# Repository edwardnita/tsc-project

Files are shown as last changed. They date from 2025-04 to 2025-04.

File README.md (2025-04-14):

# OpenBook - eBook Reader

**Autor:** Nita Eduard-Eugen
**Data:** 06 Aprilie 2025, updated pe 14 Aprilie 2025

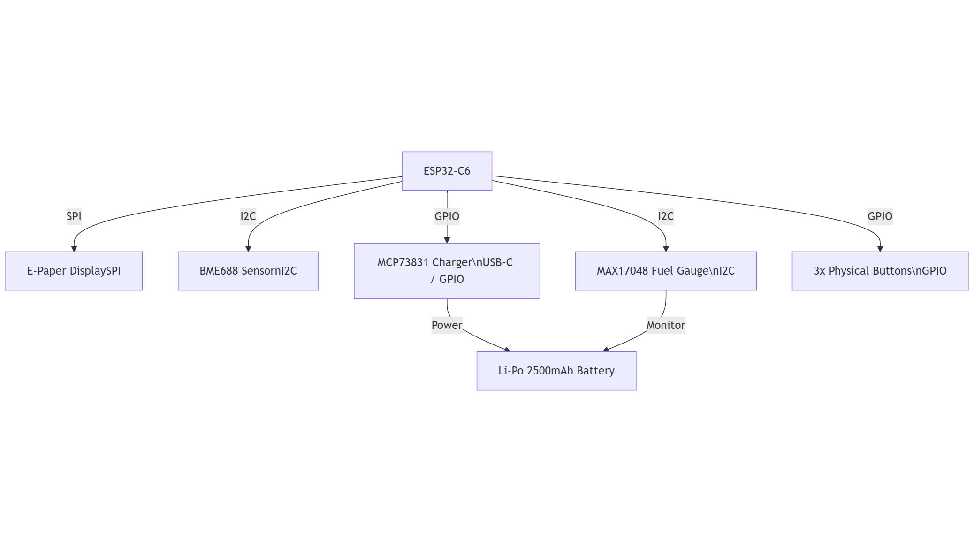
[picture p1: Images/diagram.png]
block_diagram


## Bill of Materials (BOM)

| Component | Link | Datasheet |
|:---|:---|:---|
| BME680 | [Link](https://www.snapeda.com/parts/BME680/Bosch/view-part/?welcome=home) | [Datasheet](https://www.bosch-sensortec.com/media/boschsensortec/downloads/datasheets/bst-bme680-ds001.pdf) |
| BUTTON | [Link](https://industry.panasonic.com/global/en/products/control/switch/light-touch/number/evqpuj02k) | [Datasheet](https://www.lcsc.com/datasheet/lcsc_datasheet_2201121800_PANASONIC-EVQPUJ02K_C2936858.pdf) |
| R0402 | [Link](https://componentsearchengine.com/part-view/R0402%201%25%20100%20K%20(RC0402FR-07100KL)/YAGEO) | [Datasheet](https://www.resistor.com/assets/pdf/0402tstd.pdf) |
| CPH3225A | [Link](https://www.snapeda.com/parts/CPH3225A/Seiko+Instruments/view-part/?ref=eda) | [Datasheet](https://octopart.com/datasheet/cph3225a-seiko-25340571) |
| EVQPUJ02K | [Link](https://industry.panasonic.com/global/en/products/control/switch/light-touch/number/evqpuj02k) | [Datasheet](https://www.lcsc.com/datasheet/lcsc_datasheet_2201121800_PANASONIC-EVQPUJ02K_C2936858.pdf) |
| KP-1608SURCK | [Link](https://www.snapeda.com/parts/KP-1608SURCK/Kingbright/view-part/?ref=search&t=LED%200603) | [Datasheet](https://media.elv.com/file/107153_led_surck1608_data.pdf) |
| USBLC6-2SC6Y | [Link](https://www.snapeda.com/parts/USBLC6-2SC6Y/STMicroelectronics/view-part/?ref=eda) | [Datasheet](https://www.digikey.com/en/htmldatasheets/production/1375342/0/0/1/usblc6-2sc6y) |
| SD0805S020S1R0 | [Link](https://ro.mouser.com/ProductDetail/KYOCERA-AVX/SD0805S020S1R0?qs=jCA%252BPfw4LHbpkAoSnwrdjw%3D%3D) | [Datasheet](https://www.alldatasheet.com/view.jsp?Searchword=SD0805S&sField=2) |
| PGB1010603MR | [Link](https://www.snapeda.com/parts/PGB1010603MR/Littelfuse/view-part/?ref=eda) | [Datasheet](https://www.alldatasheet.com/view.jsp?Searchword=Pgb1010603mr) |
| BD5229G-TR | [Link](https://componentsearchengine.com/part-view/BD5229G-TR/ROHM%20Semiconductor) | [Datasheet](https://www.lcsc.com/datasheet/lcsc_datasheet_2201131330_ROHM-Semicon-BD5229G-TR_C962636.pdf) |
| XC6220A331MR-G | [Link](https://componentsearchengine.com/part-view/XC6220A331MR-G/Torex) | [Datasheet](https://www.alldatasheet.com/view.jsp?Searchword=Xc6220) |
| USB4110-GF-A | [Link](https://componentsearchengine.com/part-view/USB4110-GF-A/GCT%20(GLOBAL%20CONNECTOR%20TECHNOLOGY)) | [Datasheet](https://gct.co/files/drawings/usb4110.pdf) |
| Adafruit LEDCHIP-LED0603 | [Link](https://eu.mouser.com/ProductDetail/Adafruit/4208?qs=PzGy0jfpSMtbScLbr0L5dw%3D%3D) | [Datasheet](https://www.arrow.com/en/manufacturers/adafruit-industries/datasheets) |
| Bobina | [Link](https://store.comet.srl.ro/Catalogue/Product/43497/) | [Datasheet](https://www.scribd.com/document/814581278/Datasheet-Bobina) |
| PFMF | [Link](https://www.mouser.co.uk/ProductDetail/EPCOS-TDK/B72520T0350K062?qs=dEfas%2FXlABIszF52uu7vrg%3D%3D) | [Datasheet](https://ro.mouser.com/c/ds/circuit-protection/thermistors/resettable-fuses-pptc/?m=Schurter&series=PFMF) |
| DMG2305UX-7 | [Link](https://componentsearchengine.com/part-view/DMG2305UX-7/Diodes%20Incorporated) | [Datasheet](https://www.mouser.com/datasheet/2/115/DMG2305UX-266242.pdf) |
| Si1308EDL-T1-GE3 | [Link](https://componentsearchengine.com/part-view/SI1308EDL-T1-GE3/Vishay) | [Datasheet](https://www.alldatasheet.com/view.jsp?Searchword=Si1308edl) |
| MCP73831T-5ACI/OT | [Link](https://www.mouser.co.uk/ProductDetail/Microchip-Technology/MCP73831T-5ACI-OT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) | [Datasheet](https://ww1.microchip.com/downloads/en/DeviceDoc/MCP73831-Family-Data-Sheet-DS20001984H.pdf) |
| SMD Solder | [Link](https://grabcad.com/library/solder-jumpers-1) | |
| W25Q512JVEIQ | [Link](https://www.snapeda.com/parts/ESP32-C6-WROOM-1-N8/Espressif+Systems/view-part/?ref=eda) | [Datasheet](https://www.mouser.com/datasheet/2/949/W25Q512JV_SPI_RevB_06252019_KMS-2487502.pdf) |
| ESP32-C6-WROOM-1-N8 | [Link](https://www.snapeda.com/parts/ESP32-C6-WROOM-1-N8/Espressif+Systems/view-part/?ref=eda) | [Datasheet](https://www.mouser.com/catalog/specsheets/Espressif_ESP32_C6_WROOM_1%20_Datasheet_V0.1_PRELIMINARY_en.pdf) |
| DS3231SN# | [Link](https://www.snapeda.com/parts/DS3231SN%23/Analog+Devices/view-part/?ref=eda) | [Datasheet](https://www.alldatasheet.com/view.jsp?Searchword=Ds3231sn%20datasheet) |
| MAX17048G+T10 | [Link](https://www.snapeda.com/parts/MAX17048G+T10/Analog+Devices/view-part/?ref=eda) | [Datasheet](https://www.alldatasheet.com/view.jsp?Searchword=Max17048) |

## Descriere Hardware

OpenBook este un e-reader open source care folosește ESP32-C6 ca unitate de control. Dispozitivul se concentrează pe eficiență energetică, conectivitate și afișaj de calitate tip e-ink.

### Microcontroller: ESP32-C6

- Procesor: RISC-V 32-bit @ 160 MHz
- Interfețe utilizate:
  - **SPI**: pentru e-paper
  - **I2C**: pentru BME688 și MAX17048
  - **USB-C**: pentru alimentare și transfer date
  - **GPIO**: pentru butoane și control încărcare

### Display: E-paper 7.5”

- Rezoluție: 800x480 px, alb-negru
- Interfață: SPI
- Refresh complet < 1s, parțial < 0.5s
- Folosit pentru afișare cărți, meniuri, informații senzori

### Senzor Mediu: BME688

- Măsoară: temperatură, umiditate, presiune, calitate aer (eCO2, TVOC)
- I2C, 400kHz
- Datele sunt afișate în interfața de utilizator și pot fi logate

### Power Management:

- **Baterie**: 2500mAh Li-Po 3.7V
- **MAX17048**: estimează nivelul de încărcare
- **MCP73831**: controlează încărcarea prin USB-C (1A max)
- **Consum**:
  - Active: ~120mA
  - Sleep: <50µA

### Butoane:

- 3 butoane fizice pentru meniu, navigare și selectare
- Interfață GPIO, debounce hardware/firmware

### USB-C:

- Alimentare și transfer fișiere (USB MSC)
- Protecție ESD

### PCB și Carcasă:

- PCB 2-layer cu layout optimizat termic și EMC
- ENIG finish
- Carcasă ABS/PC, 250g, ergonomică, rezistentă la praf și stropire (IP estimat: IP52)

## Pini ESP32-C6

| Componentă | Pin ESP32-C6 | Motiv Alegere |
| --- | --- | --- |
| E-Paper SPI CLK  | GPIO10 | SPI hardware |
| E-Paper SPI MOSI | GPIO11 | SPI hardware |
| E-Paper CS | GPIO9 | Chip Select dedicat |
| BME688 I2C SDA | GPIO4 | I2C standard |
| BME688 I2C SCL | GPIO5 | I2C standard |
| MAX17048 SDA | GPIO4 | I2C partajat cu BME688  |
| MAX17048 SCL | GPIO5 | I2C partajat cu BME688  |
| Buton 1 | GPIO6 | Navigare |
| Buton 2 | GPIO7 | Selectare |
| Buton 3 | GPIO8 | Back/Menu |
| USB D+ | GPIO18 | USB funcționalitate MSC |
| USB D- | GPIO19 | USB funcționalitate MSC |

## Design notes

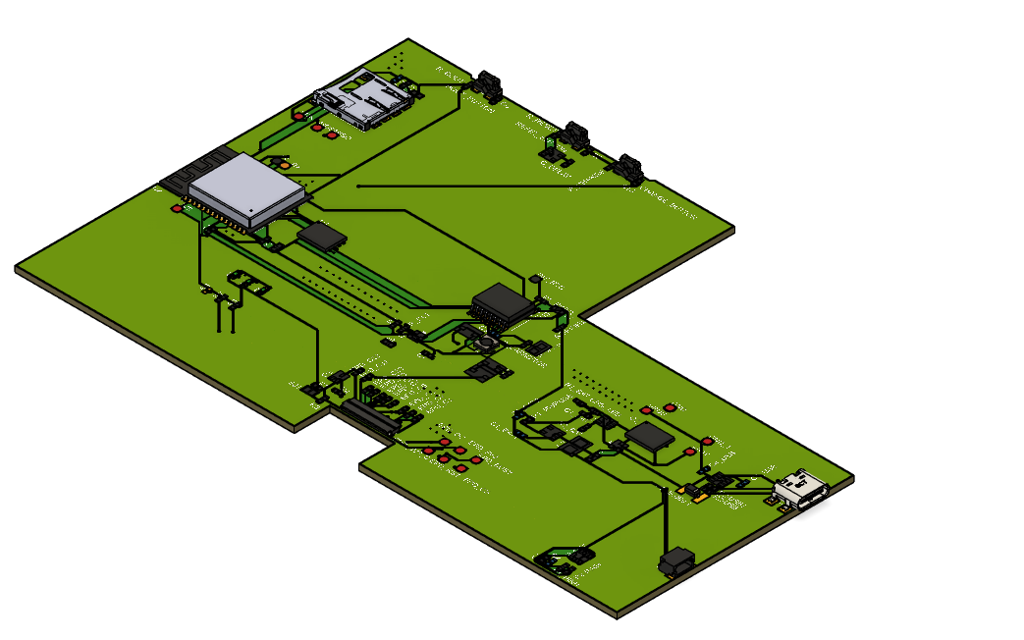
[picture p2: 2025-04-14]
Images/Board.png

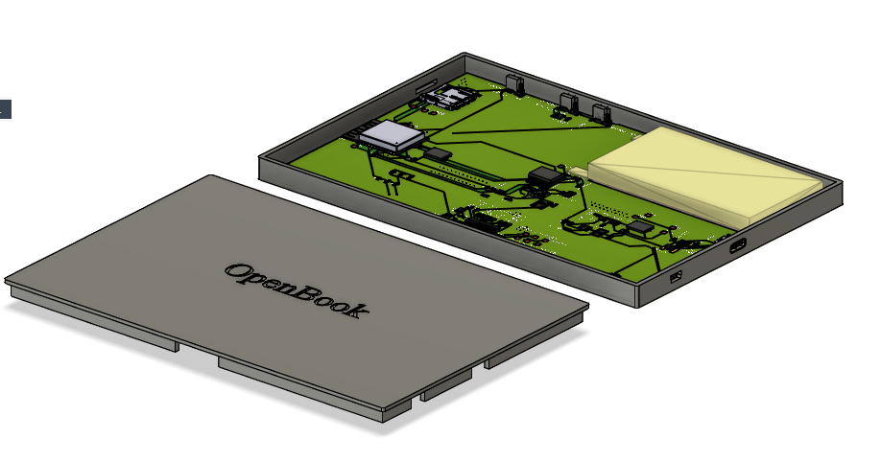
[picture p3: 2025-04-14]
Images/Full.png

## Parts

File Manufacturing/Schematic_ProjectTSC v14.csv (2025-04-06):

Qty | Value | Device | Package | Parts | Description | ARROW_PART_NUMBER | ARROW_PRICE-STOCK | AVAILABILITY | CENTROID_NOT_SPECIFIED | CHECK_PRICES | COPYRIGHT | DATASHEET | DESCRIPTION | DIGIKEY_DESCRIPTION | DIGIKEY_PART_NUMBER | HEIGHT | LEAD_FREE | MANUFACTURER_NAME | MANUFACTURER_PART_NUMBER | MF | MFR_NAME | MOUSER_PART_NUMBER | MOUSER_PRICE-STOCK | MOUSER_TESTING_PART_NUMBER | MOUSER_TESTING_PRICE-STOCK | MP | MPN | PACKAGE | POPULARITY | PREFIX | PRICE | PROD_ID | PURCHASE-URL | ROHS | SHOW | SHOW_NAME | SNAPEDA_LINK | SPICEMODEL | SPICEPREFIX | TEMPERATURE_RANGE_HIGH | TEMPERATURE_RANGE_LOW | TP_SIGNAL_NAME | VALUE
1 |  | ADAFRUIT_LEDCHIP-LED0603 | ADAFRUIT_CHIP-LED0603 | CHG_LED | LED
1 |  | SJ | SJ | SJ1 | SMD solder JUMPER |  |  |  |  |  |  |  |  |  |  |  |  |  |  |  |  |  |  |  |  |  |  |  | 3
1 | 0.1uF/50V | ESP32_WROVER_EAGLE-LTSPICE_CC0402 | ESP32_WROVER_EAGLE-LTSPICE_C0402 | EPD_C5 | CAPACITOR, European symbol |  |  |  |  |  |  |  |  |  |  |  |  |  |  |  |  |  |  |  |  |  |  |  |  |  |  |  |  |  |  |  |  | NONE | C
1 | 0.47 | ESP32_WROVER_EAGLE-LTSPICE_RR0402 | ESP32_WROVER_EAGLE-LTSPICE_R0402 | R3 | RESISTOR, European symbol |  |  |  |  |  |  |  |  |  |  |  |  |  |  |  |  |  |  |  |  |  |  |  |  |  |  |  |  |  |  |  |  | NONE | R
1 | 100k | ESP32_WROVER_EAGLE-LTSPICE_RR0402 | ESP32_WROVER_EAGLE-LTSPICE_R0402 | R1_PWRUSB | RESISTOR, European symbol |  |  |  |  |  |  |  |  |  |  |  |  |  |  |  |  |  |  |  |  |  |  |  |  |  |  |  |  |  |  |  |  | NONE | R
4 | 100nF | EAGLE-LTSPICE_CC0402 | EAGLE-LTSPICE_C0402 | C2, C4_USB, C8, C9 | CAPACITOR, European symbol |  |  |  |  |  |  |  |  |  |  |  |  |  |  |  |  |  |  |  |  |  |  |  |  |  |  |  |  |  |  |  |  | NONE | C
3 | 100nF | ESP32_WROVER_EAGLE-LTSPICE_CC0402 | ESP32_WROVER_EAGLE-LTSPICE_C0402 | C6, C10, C_DELAY | CAPACITOR, European symbol |  |  |  |  |  |  |  |  |  |  |  |  |  |  |  |  |  |  |  |  |  |  |  |  |  |  |  |  |  |  |  |  | NONE | C
1 | 100uF | EAGLE-LTSPICE_CC0402 | EAGLE-LTSPICE_C0402 | C1 | CAPACITOR, European symbol |  |  |  |  |  |  |  |  |  |  |  |  |  |  |  |  |  |  |  |  |  |  |  |  |  |  |  |  |  |  |  |  | NONE | C
1 | 100uF TANT | RCL_CPOL-EUCT3528 | RCL_CT3528 | C3 | POLARIZED CAPACITOR, European symbol |  |  |  |  |  |  |  |  |  |  |  |  |  |  |  |  |  |  |  |  |  |  |  | 0 |  |  |  |  |  |  |  |  |  | C
16 | 10K | ESP32_WROVER_EAGLE-LTSPICE_RR0402 | ESP32_WROVER_EAGLE-LTSPICE_R0402 | R1, R1_PINH, R1_PINH1, R2-PINH, R2-PINH1, R4, R5, R6, R7, R8, R9, R10, R_BOOT, R_CHANGE, R_CL1, R_RESET | RESISTOR, European symbol |  |  |  |  |  |  |  |  |  |  |  |  |  |  |  |  |  |  |  |  |  |  |  |  |  |  |  |  |  |  |  |  | NONE | R
1 | 10uF | ESP32_WROVER_EAGLE-LTSPICE_CC0402 | ESP32_WROVER_EAGLE-LTSPICE_C0402 | C7 | CAPACITOR, European symbol |  |  |  |  |  |  |  |  |  |  |  |  |  |  |  |  |  |  |  |  |  |  |  |  |  |  |  |  |  |  |  |  | NONE | C
1 | 112A-TAAR-R03_ATTEND | 112A-TAAR-R03_ATTEND | 112ATAARR03ATTEND | J4 | Micro SD Card Socket, Push-Push Type, Top Mount, SMT, H=1.83mm, 10u |  |  |  |  |  |  |  | Micro SD Card Socket | Push-Push Type | Top Mount | SMT | H=1.83mm | 10u |  |  | 1.9mm |  | ATTEND | 112A-TAAR-R03 ATTEND
1 | 15 | ESP32_WROVER_EAGLE-LTSPICE_RR0402 | ESP32_WROVER_EAGLE-LTSPICE_R0402 | R_CAPACITOR | RESISTOR, European symbol |  |  |  |  |  |  |  |  |  |  |  |  |  |  |  |  |  |  |  |  |  |  |  |  |  |  |  |  |  |  |  |  | NONE | R
1 | 1uF | ESP32_WROVER_EAGLE-LTSPICE_CC0402 | ESP32_WROVER_EAGLE-LTSPICE_C0402 | C5 | CAPACITOR, European symbol |  |  |  |  |  |  |  |  |  |  |  |  |  |  |  |  |  |  |  |  |  |  |  |  |  |  |  |  |  |  |  |  | NONE | C
9 | 1uF/50V | ESP32_WROVER_EAGLE-LTSPICE_CC0402 | ESP32_WROVER_EAGLE-LTSPICE_C0402 | EPD_C1, EPD_C2, EPD_C6, EPD_C7, EPD_C8, EPD_C9, EPD_C10, EPD_C11, EPD_C12 | CAPACITOR, European symbol |  |  |  |  |  |  |  |  |  |  |  |  |  |  |  |  |  |  |  |  |  |  |  |  |  |  |  |  |  |  |  |  | NONE | C
1 | 2.2 | ESP32_WROVER_EAGLE-LTSPICE_RR0402 | ESP32_WROVER_EAGLE-LTSPICE_R0402 | R2 | RESISTOR, European symbol |  |  |  |  |  |  |  |  |  |  |  |  |  |  |  |  |  |  |  |  |  |  |  |  |  |  |  |  |  |  |  |  | NONE | R
1 | 200 | ESP32_WROVER_EAGLE-LTSPICE_RR0402 | ESP32_WROVER_EAGLE-LTSPICE_R0402 | R1_BAT | RESISTOR, European symbol |  |  |  |  |  |  |  |  |  |  |  |  |  |  |  |  |  |  |  |  |  |  |  |  |  |  |  |  |  |  |  |  | NONE | R
2 | 20V/4.2A/52m?/1.4W | ESP32_WROVER_SPARKFUN-DISCRETESEMI_MOSFET_PCH-DMG2305UX-7 | ESP32_WROVER_SPARKFUN-DISCRETESEMI_SOT23-3 | Q1, Q2 | P-channel MOSFETs |  |  |  |  |  |  |  |  |  |  |  |  |  |  |  |  |  |  |  |  |  |  |  |  |  |  | TRAN-14388 |  |  |  |  |  |  |  |  |  |  | 20V/4.2A/52m?/1.4W
1 | 2K | ESP32_WROVER_EAGLE-LTSPICE_RR0402 | ESP32_WROVER_EAGLE-LTSPICE_R0402 | R2_BAT | RESISTOR, European symbol |  |  |  |  |  |  |  |  |  |  |  |  |  |  |  |  |  |  |  |  |  |  |  |  |  |  |  |  |  |  |  |  | NONE | R
3 | 4.7uF | EAGLE-LTSPICE_CC0402 | EAGLE-LTSPICE_C0402 | C1_BAT1, C1_BAT2, C5_USB | CAPACITOR, European symbol |  |  |  |  |  |  |  |  |  |  |  |  |  |  |  |  |  |  |  |  |  |  |  |  |  |  |  |  |  |  |  |  | NONE | C
2 | 4.7uF | ESP32_WROVER_EAGLE-LTSPICE_CC0402 | ESP32_WROVER_EAGLE-LTSPICE_C0402 | C1_BAT, C2_BAT | CAPACITOR, European symbol |  |  |  |  |  |  |  |  |  |  |  |  |  |  |  |  |  |  |  |  |  |  |  |  |  |  |  |  |  |  |  |  | NONE | C
1 | 4.7uF/25V | ESP32_WROVER_EAGLE-LTSPICE_CC0402 | ESP32_WROVER_EAGLE-LTSPICE_C0402 | C4 | CAPACITOR, European symbol |  |  |  |  |  |  |  |  |  |  |  |  |  |  |  |  |  |  |  |  |  |  |  |  |  |  |  |  |  |  |  |  | NONE | C
1 | 5K1 | ESP32_WROVER_EAGLE-LTSPICE_RR0402 | ESP32_WROVER_EAGLE-LTSPICE_R0402 | R2-USB | RESISTOR, European symbol |  |  |  |  |  |  |  |  |  |  |  |  |  |  |  |  |  |  |  |  |  |  |  |  |  |  |  |  |  |  |  |  | NONE | R
1 | 5k1 | ESP32_WROVER_EAGLE-LTSPICE_RR0402 | ESP32_WROVER_EAGLE-LTSPICE_R0402 | R2-USB1 | RESISTOR, European symbol |  |  |  |  |  |  |  |  |  |  |  |  |  |  |  |  |  |  |  |  |  |  |  |  |  |  |  |  |  |  |  |  | NONE | R
1 | 744043680IND_4828-WE-TPC_WRE | 744043680IND_4828-WE-TPC_WRE | IND_4828-WE-TPC_WRE | L1 |  |  |  |  |  |  | Copyright (C) 2024 Ultra Librarian. All rights reserved. |  |  |  |  |  |  |  | 744043680 |  | Wurth Electronics
1 | BD5229G-TR | BD5229G-TR | SOT95P280X125-5N | IC1 | Voltage Detector with Adjustable Delay Time: CMOS processes are utilized to develop high precision, low current consumption CMOS reset ICs that allow arbitrary setting of the delay time. The extensive lineup includes both Nch Open Drain and CMOS output types in a wide range of detection voltages (from 2.3V to 6.0V, in 0.1V steps), enabling selection of the ideal solution based on customer requirements. In addition, the entire series is of course both lead-free and RoHS-compliant. |  |  |  |  |  |  |  | Voltage Detector with Adjustable Delay Time: CMOS processes are utilized to develop high precision | low current consumption CMOS reset ICs that allow arbitrary setting of the delay time. The extensive lineup includes both Nch Open Drain and CMOS output types in a wide range of detection voltages (from 2.3V to 6.0V | in 0.1V steps) | enabling selection of the ideal solution based on customer requirements. In addition | the entire series is of course both lead-free and RoHS-compliant. |  |  | 1.25mm |  | ROHM Semiconductor | BD5229G-TR |  |  | 755-BD5229G-TR | https://www.mouser.co.uk/ProductDetail/ROHM-Semiconductor/BD5229G-TR?qs=4kLU8WoGk0vvnhrrYwdszw%3D%3D
2 | BUTTON_CUSYOMV1 | BUTTON_CUSYOMV1 | MYBUTTON | BOOT_BUTTON, CHANGE_BUTTON
1 | BUTTON_CUSYOMV1 | BUTTON_CUSYOMV1 | MYBUTTON | RESET_BUTTON |  |  |  |  |  |  |  |  |  |  |  |  |  |  |  |  |  |  |  |  |  |  |  |  |  |  |  |  |  |  |  | RESET_BUTTON
1 | CPH3225A | CPH3225A | CAPCP3225X100N | C10_SUPERCAP | Cap 0.011F 3.3V 1210 Flat Check availability |  |  | Not in stock |  | https://www.snapeda.com/parts/CPH3225A/Seiko+Instruments/view-part/?ref=eda |  |  | 11 mF (EDLC) Supercapacitor 3.3 V 1210 (3225 Metric) - - |  |  |  |  |  |  | Seiko Instruments |  |  |  |  |  | CPH3225A |  | 1210 Seiko |  |  | None |  | https://www.snapeda.com/api/url_track_click_mouser/?unipart_id=562593&manufacturer=Seiko Instruments&part_name=CPH3225A&search_term=None |  |  |  | https://www.snapeda.com/parts/CPH3225A/Seiko+Instruments/view-part/?ref=snap
1 | DS3231SN# | DS3231SN# | SOIC127P1032X265-16N | U3 | Real Time Clock Serial 16-Pin SOIC W T/R Check availability |  |  | In Stock |  | https://www.snapeda.com/parts/DS3231SN%23/Analog+Devices/view-part/?ref=eda |  |  | Extremely Accurate I2C-Integrated RTC/TCXO/Crystal |  |  |  |  |  |  | Analog Devices |  |  |  |  |  | DS3231SN# |  | SOIC-16 Maxim |  |  | None |  | https://www.snapeda.com/api/url_track_click_mouser/?unipart_id=99048&manufacturer=Analog Devices&part_name=DS3231SN#&search_term=None |  |  |  | https://www.snapeda.com/parts/DS3231SN%23/Analog+Devices/view-part/?ref=snap
1 | ESP32-C6-WROOM-1-N8 | ESP32-C6-WROOM-1-N8 | XCVR_ESP32-C6-WROOM-1-N8 | U2 | Check availability |  |  | In Stock |  | https://www.snapeda.com/parts/ESP32-C6-WROOM-1-N8/Espressif+Systems/view-part/?ref=eda |  |  | Multiprotocol Modules ESP32-C6 module | Wi-Fi 6 in 2.4 GHz band | Bluetooth 5 | Zigbee 3.0 and Thread. ESP34-WROOM Compatible - ENGINEERING SAMPLE |  |  |  |  |  |  | Espressif Systems |  |  |  |  |  | ESP32-C6-WROOM-1-N8 |  | None |  |  | None |  |  |  |  |  | https://www.snapeda.com/parts/ESP32-C6-WROOM-1-N8/Espressif+Systems/view-part/?ref=snap
1 | ESP32C6_VARISTORCN1812 | ESP32C6_VARISTORCN1812 | ESP32C6_VARISTOR_CT/CN1812 | PFMF.050.1 | VARISTOR |  |  |  |  |  |  |  |  |  |  |  |  |  |  |  |  |  |  |  |  |  |  |  | 0
1 | ESP32_WROVER_AVX---SD0805S020S1R0_AVX_SD0805S020S1R0_0_0AVX_SD0805S020S1R0_0_0 | ESP32_WROVER_AVX---SD0805S020S1R0_AVX_SD0805S020S1R0_0_0AVX_SD0805S020S1R0_0_0 | ESP32_WROVER_AVX---SD0805S020S1R0_AVX_SD0805S020S1R0_0 | D7 | Schottky Barrier Rectifier Diode |  |  |  | No |  |  | http://datasheets.avx.com/schottky.pdf |  | DIODE SCHOTTKY 20V 1A 0805 | 478-7800-1-ND |  | yes |  |  | AVX |  | 581-SD0805S020S1R0 |  |  |  |  |  | 0805 (2012 metric) |  | D |  |  |  | yes |  |  |  |  |  | +125°C | -55°C
1 | ESP32_WROVER_AVX---SD0805S020S1R0_AVX_SD0805S020S1R0_0_0AVX_SD0805S020S1R0_0_0 | ESP32_WROVER_AVX---SD0805S020S1R0_AVX_SD0805S020S1R0_0_0AVX_SD0805S020S1R0_0_0 | ESP32_WROVER_AVX---SD0805S020S1R0_AVX_SD0805S020S1R0_0 | D2 | Schottky Barrier Rectifier Diode |  |  |  | No |  |  | http://datasheets.avx.com/schottky.pdf |  | DIODE SCHOTTKY 20V 1A 0805 | 478-7800-1-ND |  | yes |  |  | AVX |  | 581-SD0805S020S1R0 |  |  |  |  |  | 0805 (2012 metric) |  | D |  |  |  | yes | SD0805S020S1R0 |  |  |  |  | +125°C | -55°C
1 | ESP32_WROVER_BME680_BME680 | ESP32_WROVER_BME680_BME680 | ESP32_WROVER_BME680_PSON80P300X300X100-8N | SENSOR2 | Integrated Environmental Unit |  |  | Unavailable |  |  |  |  | Integrated Environmental Unit |  |  |  |  |  |  | Bosch Sensortec |  |  |  |  |  | BME680 |  | LGA-8 Bosch Tools |  |  | None
1 | ESP32_WROVER_SPARKFUN-IC-POWER_MCP73831 | ESP32_WROVER_SPARKFUN-IC-POWER_MCP73831 | ESP32_WROVER_SPARKFUN-IC-POWER_SOT23-5 | U10 | MCP73831T Li-Ion, Li-Pol Controller |  |  |  |  |  |  |  |  |  |  |  |  |  |  |  |  |  |  |  |  |  |  |  |  |  |  | IC-09995
1 | FH34SRJ-24S-0.5SH_99_ | FH34SRJ-24S-0.5SH_99_ | FH34SRJ24S05SH99 | J1 | (0.50mm) Surface Mount, Right Angle |  |  |  |  |  |  |  | 24 Position FFC | FPC Connector Contacts | (0.50mm) Surface Mount | Right Angle |  |  | 1.1mm |  | Hirose | FH34SRJ-24S-0.5SH(99) |  |  | 798-FH34SRJ24S05SH99 | https://www.mouser.co.uk/ProductDetail/Hirose-Connector/FH34SRJ-24S-0.5SH99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
1 | MAX17048G+T10 | MAX17048G+T10 | SON50P200X200X80-9N | U4 | Check availability |  |  | In Stock |  | https://www.snapeda.com/parts/MAX17048G+T10/Analog+Devices/view-part/?ref=eda |  |  | 3µA 1-Cell/2-Cell Fuel Gauge with ModelGauge |  |  |  |  |  |  | Analog Devices |  |  |  |  |  | MAX17048G+T10 |  | TDFN-8 Maxim |  |  | None |  | https://www.snapeda.com/api/url_track_click_mouser/?unipart_id=329239&manufacturer=Analog Devices&part_name=MAX17048G+T10&search_term=None |  |  |  | https://www.snapeda.com/parts/MAX17048G+T10/Analog+Devices/view-part/?ref=snap
3 | MBR0530 | MBR0530 | SOD3716X135N | D3, D4, D5 | ON SEMICONDUCTOR - MBR0530 - DIODE, SCHOTTKY, 0.5A, 30V, SOD-123 |  |  | In Stock |  | https://www.snapeda.com/parts/MBR0530/Onsemi/view-part/?ref=eda |  |  | Diode Schottky 30 V 500mA Surface Mount SOD-123 |  |  |  |  |  |  | ON Semiconductor |  |  |  |  |  | MBR0530 |  | SOD-123-2 ON Semiconductor |  |  | None |  | https://www.snapeda.com/api/url_track_click_mouser/?unipart_id=179458&manufacturer=ON Semiconductor&part_name=MBR0530&search_term=None |  |  |  | https://www.snapeda.com/parts/MBR0530/Onsemi/view-part/?ref=snap
6 | PGB1010603MR | PGB1010603MR | DIOC1608X36N | D6, D8, D9, D10, D11, D12 | Check availability |  |  | In Stock |  | https://www.snapeda.com/parts/PGB1010603MR/Littelfuse/view-part/?ref=eda |  |  | 150V (Typ) Clamp - Ipp Tvs Diode Surface Mount 0603 (1608 Metric) |  |  |  |  |  |  | Littelfuse Inc. |  |  |  |  |  | PGB1010603MR |  | 0603 Littelfuse Inc. |  |  | None |  | https://www.snapeda.com/api/url_track_click_mouser/?unipart_id=5659453&manufacturer=Littelfuse Inc.&part_name=PGB1010603MR&search_term=None |  |  |  | https://www.snapeda.com/parts/PGB1010603MR/Littelfuse/view-part/?ref=snap
1 | QWIIC_RIGHT_ANGLE | QWIIC_CONNECTORJS-1MM | JST04_1MM_RA | J3 | SparkFun I2C Standard Qwiic Connector |  |  |  |  |  |  |  |  |  |  |  |  |  |  |  |  |  |  |  |  |  |  |  |  |  |  | CONN-13694 |  |  |  |  |  |  |  |  |  |  | QWIIC_RIGHT_ANGLE
1 | SAMACSYS_PARTS_USB4110-GF-A | SAMACSYS_PARTS_USB4110-GF-A | SAMACSYS_PARTS_USB4110GFA | J2 | CONN USB 2.0 TYPE-C R/A SMT |  |  |  |  |  |  |  | CONN USB 2.0 TYPE-C R/A SMT |  |  | 3.26mm |  | GCT (GLOBAL CONNECTOR TECHNOLOGY) | USB4110-GF-A |  |  | 640-USB4110-GF-A | https://www.mouser.co.uk/ProductDetail/GCT/USB4110-GF-A?qs=KUoIvG%2F9IlYiZvIXQjyJeA%3D%3D
1 | SI1308EDL-T1-GE3 | SI1308EDL-T1-GE3 | SOT65P210X110-3N | Q3 | MOSFET N-Ch 30V 1.5A TrenchFET SC70 Vishay Si1308EDL-T1-GE3 N-channel MOSFET Transistor, 1.5 A, 30 V, 3-Pin SC-70 |  |  | In Stock |  | https://www.snapeda.com/parts/SI1308EDL-T1-GE3/Vishay+Siliconix/view-part/?ref=eda |  |  | Si1308EDL-T1-GE3 N-channel MOSFET Transistor | 1.5 A | 30 V | 3-Pin SC-70 | Siliconix / Vishay SI1308EDL-T1-GE3 |  |  |  |  |  |  | Vishay Siliconix |  |  |  |  |  | SI1308EDL-T1-GE3 |  | SOT-323 Vishay Semiconductor |  |  | None |  | https://www.snapeda.com/api/url_track_click_mouser/?unipart_id=274603&manufacturer=Vishay Siliconix&part_name=SI1308EDL-T1-GE3&search_term=None |  |  |  | https://www.snapeda.com/parts/SI1308EDL-T1-GE3/Vishay+Siliconix/view-part/?ref=snap
17 | TPTP20R | TPTP20R | TP20R | 3V3, EPD_3V3, EPD_3V3_C, EPD_BUSY, EPD_CS, EPD_DC, EPD_RST, GND, GND_1, INT_RTC, MISO, MOSI, RX, SCK, TX, VBAT, VBUS | Test pad |  |  |  |  |  |  |  |  |  |  |  |  |  |  |  |  |  |  |  |  |  |  |  | 2
1 | USBLC6-2SC6Y | USBLC6-2SC6Y | SOT95P280X145-6N | D1 | Low Cap. ESD Protection Auto SOT-23-6 STMicroelectronics USBLC6-2SC6Y, Dual Uni-Directional TVS Diode Array, 6-Pin SOT-23 |  |  | In Stock |  | https://www.snapeda.com/parts/USBLC6-2SC6Y/STMicroelectronics/view-part/?ref=eda |  |  | 17V Clamp 5A (8/20µs) Ipp Tvs Diode Surface Mount SOT-23-6 |  |  |  |  |  |  | STMicroelectronics |  |  |  |  |  | USBLC6-2SC6Y |  | SOT-23-6 STMicroelectronics |  |  | None |  |  |  |  |  | https://www.snapeda.com/parts/USBLC6-2SC6Y/STMicroelectronics/view-part/?ref=snap
1 | W25Q512JVEIQ | W25Q512JVEIQ | SON127P600X800X80-9N | U1 | Check availability |  |  | In Stock |  | https://www.snapeda.com/parts/W25Q512JVEIQ/Winbond+Electronics/view-part/?ref=eda |  |  | FLASH - NOR Memory IC 512Mb (64M x 8) SPI - Quad I/O 133 MHz 8-WSON (8x6) |  |  |  |  |  |  | Winbond Electronics |  |  |  |  |  | W25Q512JVEIQ |  | Package |  |  | None |  |  |  |  |  | https://www.snapeda.com/parts/W25Q512JVEIQ/Winbond+Electronics/view-part/?ref=snap
1 | XC6220A331MR-G | XC6220A331MR-G | SOT95P280X120-5N | IC4 | LDO Voltage Regulators |  |  |  |  |  |  |  | LDO Voltage Regulators |  |  | 1.2mm |  | Torex | XC6220A331MR-G |  |  | 865-XC6220A331MR-G | https://www.mouser.co.uk/ProductDetail/Torex-Semiconductor/XC6220A331MR-G?qs=AsjdqWjXhJ8ZSWznL1J0gg%3D%3D

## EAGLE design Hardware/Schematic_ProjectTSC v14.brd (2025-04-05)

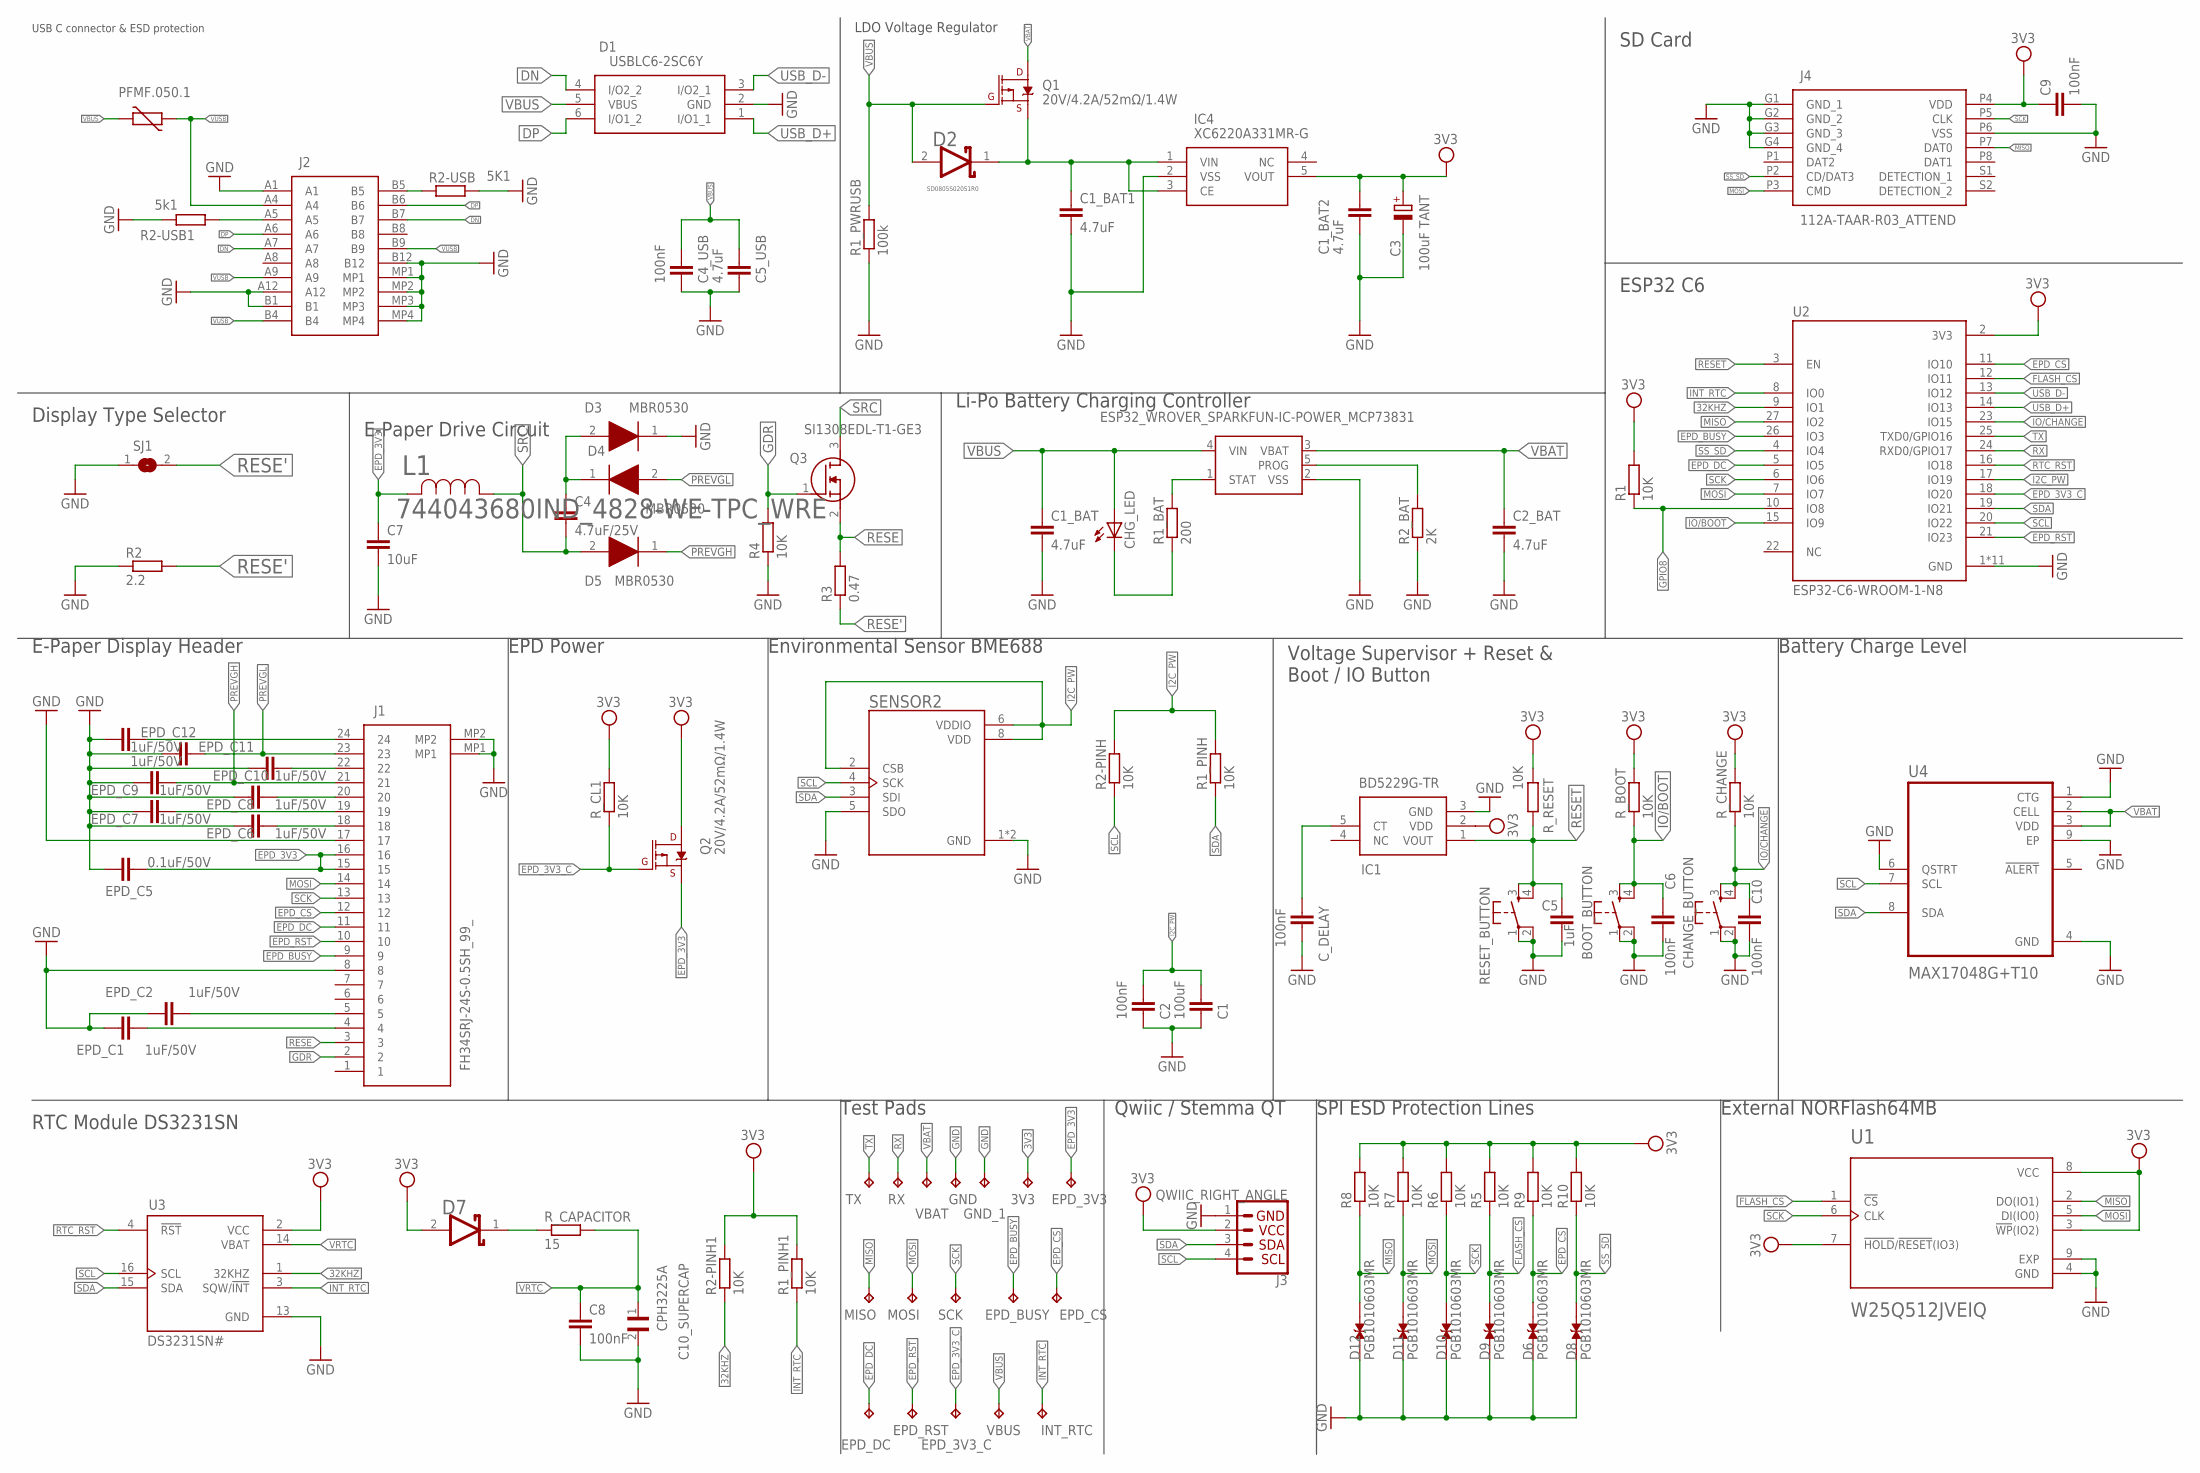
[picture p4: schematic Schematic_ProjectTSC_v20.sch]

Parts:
3V3: TPTP20R; TP20R
BOOT_BUTTON: BUTTON_CUSYOMV1; MYBUTTON
C1: 100uF; EAGLE-LTSPICE_C0402
C1_BAT, C2_BAT: 4.7uF; ESP32_WROVER_EAGLE-LTSPICE_C0402
C1_BAT1, C1_BAT2, C5_USB: 4.7uF; EAGLE-LTSPICE_C0402
C2, C4_USB, C8, C9: 100nF; EAGLE-LTSPICE_C0402
C3: 100uF TANT; RCL_CT3528
C4: 4.7uF/25V; ESP32_WROVER_EAGLE-LTSPICE_C0402
C5: 1uF; ESP32_WROVER_EAGLE-LTSPICE_C0402
C6, C10: 100nF; ESP32_WROVER_EAGLE-LTSPICE_C0402
C7: 10uF; ESP32_WROVER_EAGLE-LTSPICE_C0402
C10_SUPERCAP: CPH3225A; CAPCP3225X100N
CHANGE_BUTTON: BUTTON_CUSYOMV1; MYBUTTON
CHG_LED: ADAFRUIT_LEDCHIP-LED0603; ADAFRUIT_CHIP-LED0603
C_DELAY: 100nF; ESP32_WROVER_EAGLE-LTSPICE_C0402
D1: USBLC6-2SC6Y; SOT95P280X145-6N
D2, D7: ESP32_WROVER_AVX---SD0805S020S1R0_AVX_SD0805S020S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; ESP32_WROVER_AVX---SD0805S020S1R0_AVX_SD0805S020S1R0_0
D3, D4, D5: MBR0530; SOD3716X135N
D6, D8, D9, D10, D11, D12: PGB1010603MR; DIOC1608X36N
EPD_3V3, EPD_3V3_C: TPTP20R; TP20R
EPD_BUSY: TPTP20R; TP20R
EPD_C1, EPD_C2, EPD_C6, EPD_C7, EPD_C8, EPD_C9, EPD_C10, EPD_C11, EPD_C12: 1uF/50V; ESP32_WROVER_EAGLE-LTSPICE_C0402
EPD_C5: 0.1uF/50V; ESP32_WROVER_EAGLE-LTSPICE_C0402
EPD_CS: TPTP20R; TP20R
EPD_DC: TPTP20R; TP20R
EPD_RST: TPTP20R; TP20R
GND: TPTP20R; TP20R
GND_1: TPTP20R; TP20R
IC1: BD5229G-TR; SOT95P280X125-5N
IC4: XC6220A331MR-G; SOT95P280X120-5N
INT_RTC: TPTP20R; TP20R
J1: FH34SRJ-24S-0.5SH_99_; FH34SRJ24S05SH99
J2: SAMACSYS_PARTS_USB4110-GF-A; SAMACSYS_PARTS_USB4110GFA
J3: QWIIC_RIGHT_ANGLE; JST04_1MM_RA
J4: 112A-TAAR-R03_ATTEND; 112ATAARR03ATTEND
L1: 744043680IND_4828-WE-TPC_WRE; IND_4828-WE-TPC_WRE
MISO: TPTP20R; TP20R
MOSI: TPTP20R; TP20R
PFMF.050.1: ESP32C6_VARISTORCN1812; ESP32C6_VARISTOR_CT/CN1812
Q1, Q2: 20V/4.2A/52mΩ/1.4W; ESP32_WROVER_SPARKFUN-DISCRETESEMI_SOT23-3
Q3: SI1308EDL-T1-GE3; SOT65P210X110-3N
R1, R1_PINH, R1_PINH1, R2-PINH, R2-PINH1, R4, R5, R6, R7, R8, R9, R10: 10K; ESP32_WROVER_EAGLE-LTSPICE_R0402
R1_BAT: 200; ESP32_WROVER_EAGLE-LTSPICE_R0402
R1_PWRUSB: 100k; ESP32_WROVER_EAGLE-LTSPICE_R0402
R2: 2.2; ESP32_WROVER_EAGLE-LTSPICE_R0402
R2-USB: 5K1; ESP32_WROVER_EAGLE-LTSPICE_R0402
R2-USB1: 5k1; ESP32_WROVER_EAGLE-LTSPICE_R0402
R2_BAT: 2K; ESP32_WROVER_EAGLE-LTSPICE_R0402
R3: 0.47; ESP32_WROVER_EAGLE-LTSPICE_R0402
RESET_BUTTON: BUTTON_CUSYOMV1; MYBUTTON
RX: TPTP20R; TP20R
R_BOOT: 10K; ESP32_WROVER_EAGLE-LTSPICE_R0402
R_CAPACITOR: 15; ESP32_WROVER_EAGLE-LTSPICE_R0402
R_CHANGE: 10K; ESP32_WROVER_EAGLE-LTSPICE_R0402
R_CL1: 10K; ESP32_WROVER_EAGLE-LTSPICE_R0402
R_RESET: 10K; ESP32_WROVER_EAGLE-LTSPICE_R0402
SCK: TPTP20R; TP20R
SENSOR2: ESP32_WROVER_BME680_BME680; ESP32_WROVER_BME680_PSON80P300X300X100-8N
SJ1: SJ
TX: TPTP20R; TP20R
U1: W25Q512JVEIQ; SON127P600X800X80-9N
U2: ESP32-C6-WROOM-1-N8; XCVR_ESP32-C6-WROOM-1-N8
U3: DS3231SN#; SOIC127P1032X265-16N
U4: MAX17048G+T10; SON50P200X200X80-9N
U10: ESP32_WROVER_SPARKFUN-IC-POWER_MCP73831; ESP32_WROVER_SPARKFUN-IC-POWER_SOT23-5
VBAT: TPTP20R; TP20R
VBUS: TPTP20R; TP20R

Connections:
3V3: 3V3.TP, C1_BAT2.1, C3.+, C9.1, D7.2 (ANODE), IC1.2 (VDD), IC4.5 (VOUT), J3.2, J4.P4 (VDD), Q2.3 (D), R1.2, R1_PINH1.2, R2-PINH1.2, R5.2, R6.2, R7.2, R8.2, R9.2, R10.2, R_BOOT.2, R_CHANGE.2, R_CL1.2, R_RESET.2, U1.3 (!WP!(IO2)), U1.7 (!HOLD!/!RESET!(IO3)), U1.8 (VCC), U2.2 (3V3), U3.2 (VCC)
32KHZ: R2-PINH1.1, U2.9 (IO1), U3.1 (32KHZ)
DN: D1.4 (I/O2_2), J2.A7, J2.B7
DP: D1.6 (I/O1_2), J2.A6, J2.B6
EPD_3V3: C7.1, EPD_3V3.TP, EPD_C5.1, J1.15, J1.16, L1.2, Q2.2 (S)
EPD_3V3_C: EPD_3V3_C.TP, Q2.1 (G), R_CL1.1, U2.18 (IO20)
EPD_BUSY: EPD_BUSY.TP, J1.9, U2.26 (IO3)
EPD_CS: D6.2, EPD_CS.TP, J1.12, R9.1, U2.11 (IO10)
EPD_DC: EPD_DC.TP, J1.11, U2.5 (IO5)
EPD_RST: EPD_RST.TP, J1.10, U2.21 (IO23)
FLASH_CS: D9.2, R5.1, U1.1 (!CS), U2.12 (IO11)
GDR: J1.2, Q3.1 (G), R4.2
GND: BOOT_BUTTON.1, BOOT_BUTTON.2, C1.2, C1_BAT.2, C1_BAT1.2, C1_BAT2.2, C2.2, C2_BAT.2, C3.-, C4_USB.2, C5.2, C5_USB.2, C6.2, C7.2, C8.2, C9.2, C10.2, C10_SUPERCAP.2, CHANGE_BUTTON.1, CHANGE_BUTTON.2, C_DELAY.2, D1.2 (GND), D3.1 (K), D6.1, D8.1, D9.1, D10.1, D11.1, D12.1, EPD_C1.2, EPD_C2.2, EPD_C5.2, EPD_C6.2, EPD_C7.2, EPD_C8.2, EPD_C9.2, EPD_C10.2, EPD_C11.2, EPD_C12.2, GND.TP, GND_1.TP, IC1.3 (GND), IC4.2 (VSS), J1.8, J1.17, J1.MP1, J1.MP2, J2.A1, J2.A12, J2.B1, J2.B12, J2.MP1, J2.MP2, J2.MP3, J2.MP4, J3.1, J4.G1 (GND_1), J4.G2 (GND_2), J4.G3 (GND_3), J4.G4 (GND_4), J4.P6 (VSS), R1_PWRUSB.1, R2.1, R2-USB.2, R2-USB1.1, R2_BAT.1, R4.1, RESET_BUTTON.1, RESET_BUTTON.2, SENSOR2.1 (GND), SENSOR2.5 (SDO), SENSOR2.7 (GND), SJ1.1, U1.4 (GND), U1.9 (EXP), U2.1 (GND), U2.28 (GND), U2.29_1 (GND), U2.29_2 (GND), U2.29_3 (GND), U2.29_4 (GND), U2.29_5 (GND), U2.29_6 (GND), U2.29_7 (GND), U2.29_8 (GND), U2.29_9 (GND), U3.13 (GND), U4.1 (CTG), U4.4 (GND), U4.6 (QSTRT), U4.9 (EP), U10.2 (VSS)
GPIO8: R1.1, U2.10 (IO8)
I2C_PW: R1_PINH.2, R2-PINH.2, SENSOR2.2 (CSB), SENSOR2.6 (VDDIO), SENSOR2.8 (VDD), U2.17 (IO19)
INT_RTC: INT_RTC.TP, R1_PINH1.1, U2.8 (IO0), U3.3 (SQW/!INT)
IO/BOOT: BOOT_BUTTON.3, BOOT_BUTTON.4, C6.1, R_BOOT.1, U2.15 (IO9)
IO/CHANGE: C10.1, CHANGE_BUTTON.3, CHANGE_BUTTON.4, R_CHANGE.1, U2.23 (IO15)
MISO: D12.2, J4.P7 (DAT0), MISO.TP, R8.1, U1.2 (DO(IO1)), U2.27 (IO2)
MOSI: D11.2, J1.14, J4.P3 (CMD), MOSI.TP, R7.1, U1.5 (DI(IO0)), U2.7 (IO7)
unnamed: C1_BAT1.1, D2.1 (CATHODE), IC4.1 (VIN), IC4.3 (CE), Q1.2 (S)
unnamed: J2.B5, R2-USB.1
unnamed: R2_BAT.2, U10.5 (PROG)
unnamed: J2.A5, R2-USB1.2
unnamed: C1.1, C2.1
unnamed: C4.1, D3.2 (A), D4.1 (K)
unnamed: C_DELAY.1, IC1.5 (CT)
unnamed: CHG_LED.C, R1_BAT.1
unnamed: R1_BAT.2, U10.1 (STAT)
unnamed: EPD_C2.1, J1.5
unnamed: EPD_C1.1, J1.4
unnamed: EPD_C12.1, J1.24
unnamed: D7.1 (CATHODE), R_CAPACITOR.1
unnamed: EPD_C10.1, J1.22
unnamed: EPD_C8.1, J1.20
unnamed: EPD_C7.1, J1.19
unnamed: EPD_C6.1, J1.18
PREVGH: D5.1 (K), EPD_C9.1, J1.21
PREVGL: D4.2 (A), EPD_C11.1, J1.23
RESE: J1.3, Q3.2 (S), R3.2
RESE': R2.2, R3.1, SJ1.2
RESET: C5.1, IC1.1 (VOUT), RESET_BUTTON.3, RESET_BUTTON.4, R_RESET.1, U2.3 (EN)
RTC_RST: U2.16 (IO18), U3.4 (!RST)
RX: RX.TP, U2.24 (RXD0/GPIO17)
SCK: D10.2, J1.13, J4.P5 (CLK), R6.1, SCK.TP, U1.6 (CLK), U2.6 (IO6)
SCL: J3.4, R2-PINH.1, SENSOR2.4 (SCK), U2.20 (IO22), U3.16 (SCL), U4.7 (SCL)
SDA: J3.3, R1_PINH.1, SENSOR2.3 (SDI), U2.19 (IO21), U3.15 (SDA), U4.8 (SDA)
SRC: C4.2, D5.2 (A), L1.1, Q3.3 (D)
SS_SD: D8.2, J4.P2 (CD/DAT3), R10.1, U2.4 (IO4)
TX: TX.TP, U2.25 (TXD0/GPIO16)
USB_D+: D1.1 (I/O1_1), U2.14 (IO13)
USB_D-: D1.3 (I/O2_1), U2.13 (IO12)
VBAT: C2_BAT.1, Q1.3 (D), U4.2 (CELL), U4.3 (VDD), U10.3 (VBAT), VBAT.TP
VBUS: C1_BAT.1, C4_USB.1, C5_USB.1, CHG_LED.A, D1.5 (VBUS), D2.2 (ANODE), PFMF.050.1.2, Q1.1 (G), R1_PWRUSB.2, U10.4 (VIN), VBUS.TP
VRTC: C8.1, C10_SUPERCAP.1, R_CAPACITOR.2, U3.14 (VBAT)
VUSB: J2.A4, J2.A9, J2.B4, J2.B9, PFMF.050.1.1

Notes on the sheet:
USB C connector & ESD protection
LDO Voltage Regulator
SD Card
ESP32 C6
Display Type Selector
E-Paper Drive Circuit
Li-Po Battery Charging Controller
E-Paper Display Header
EPD Power
Environmental Sensor BME688
Voltage Supervisor + Reset & Boot / IO Button
Battery Charge Level
External NORFlash64MB
SPI ESD Protection Lines
Qwiic / Stemma QT
Test Pads
RTC Module DS3231SN

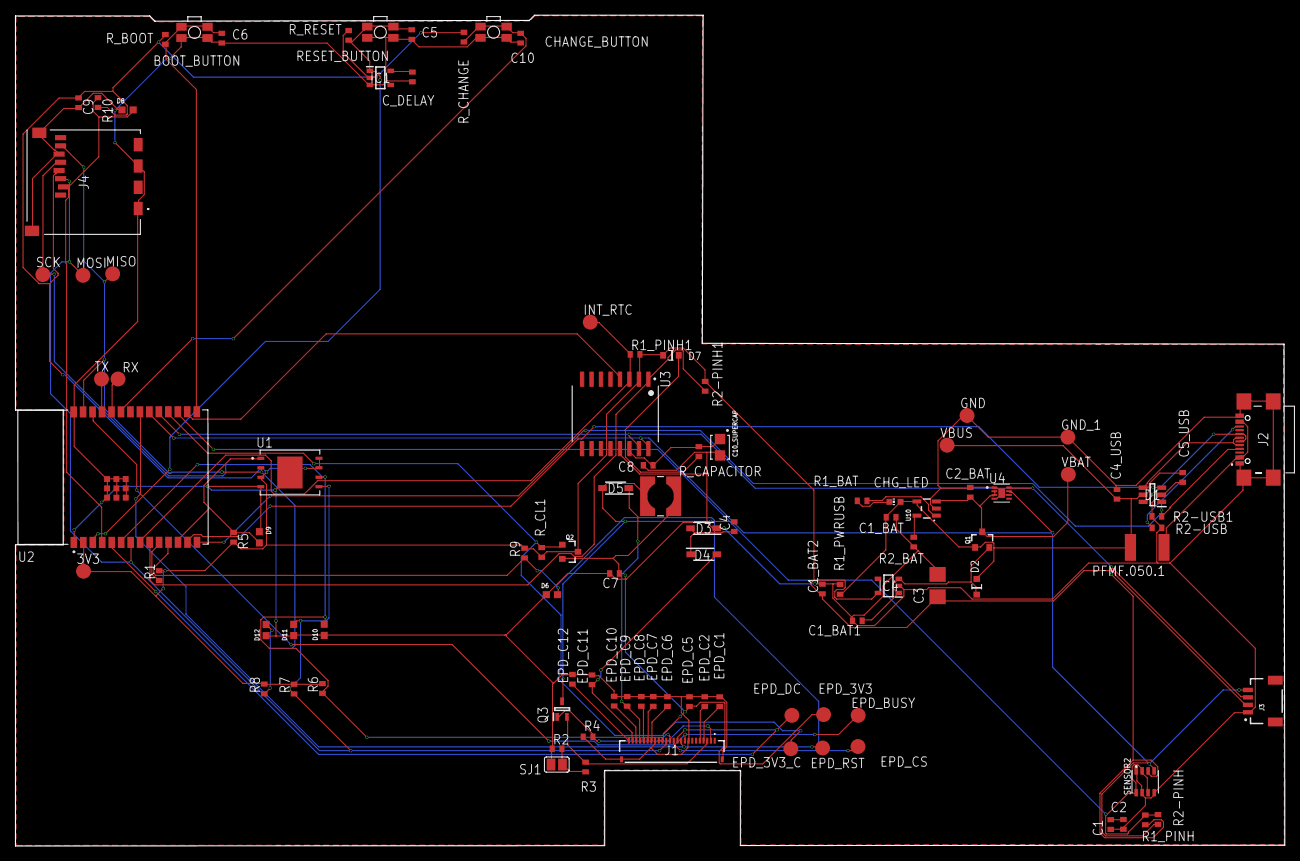
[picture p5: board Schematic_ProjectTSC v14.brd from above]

Board: 2 copper layers, 170.2 x 111.4 mm, 103 parts (0 on the bottom side), 56 nets.

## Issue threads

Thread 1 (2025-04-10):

formatare README

MariaDinu11, 2025-04-10:
Nu este formatat  tabelul de BOM
Poate fi ajustata si formatarea intregului README cu adaugarea tuturor punctelor de atins din enunt.

edwardnita, 2025-04-14:
Readme-ul a fost actualizat cu ultimul push

Closed 2025-04-14.

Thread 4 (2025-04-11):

Incadrare componente in carcasa

MariaDinu11, 2025-04-11:
Nu sunt adaugate componentele 3D, asa ca nu se poate valida pozitionarea pieselor in carcasa. Dupa adaugarea lor sa se potriveasca cu atentie cu taieturile de pe margine.

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

edwardnita, 2025-04-14:
Au fost adaugate componentele si pozitionate corespunzator:

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

Closed 2025-04-14.

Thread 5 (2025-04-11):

Via stitching

MariaDinu11, 2025-04-11:
Nu este neaparat o problema, dar undeva in zona centrala a placii (pe langa U1) este o zona destul de mare fara stitching intre planele GND top si bottom.

Nu este necesara o modificare, dar  ar putea fi o îmbunatatire utila, din punct de vedere al continuitătii planului de masa, sa fie adaugate.

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

edwardnita, 2025-04-13:
Am adus imbunatatiri pe ambele parti ale planului de masa, reducand zonele neacoperite via Stitching. Modificarile se pot regasi cu următorul push.

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

Closed 2025-04-13.

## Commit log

2025-04-01 Added schematics file
    [Schematic_ProjectTSC v14.sch]
2025-04-05 Added .brd file
    [Schematic_ProjectTSC_v12.brd]
2025-04-06 Structured the files and readme
    [PnP_Schematic_ProjectTSC v14_front.csv, Schematic_ProjectTSC v14.brd, Schematic_ProjectTSC v14.csv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]

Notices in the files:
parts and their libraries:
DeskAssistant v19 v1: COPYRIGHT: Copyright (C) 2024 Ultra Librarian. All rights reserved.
